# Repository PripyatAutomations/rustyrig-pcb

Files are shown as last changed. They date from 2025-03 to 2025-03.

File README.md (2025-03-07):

You probably want no part of this.
I'm learning KiCad by cobbling together some radio bits to hook to my USRP...

Eventually this might become a free standing transceiver for use with a host
computer for remote operation.

There is no front panel user interface, besides power LED and fault # LED
display.

-------------------------------------------

Current experiment consists of the following bits:
* raspberry pi 4b 8gb running devuan 64bit
* radioberry v2 RF frontend
* the RF amplifier, filters, and antenna matching unit.

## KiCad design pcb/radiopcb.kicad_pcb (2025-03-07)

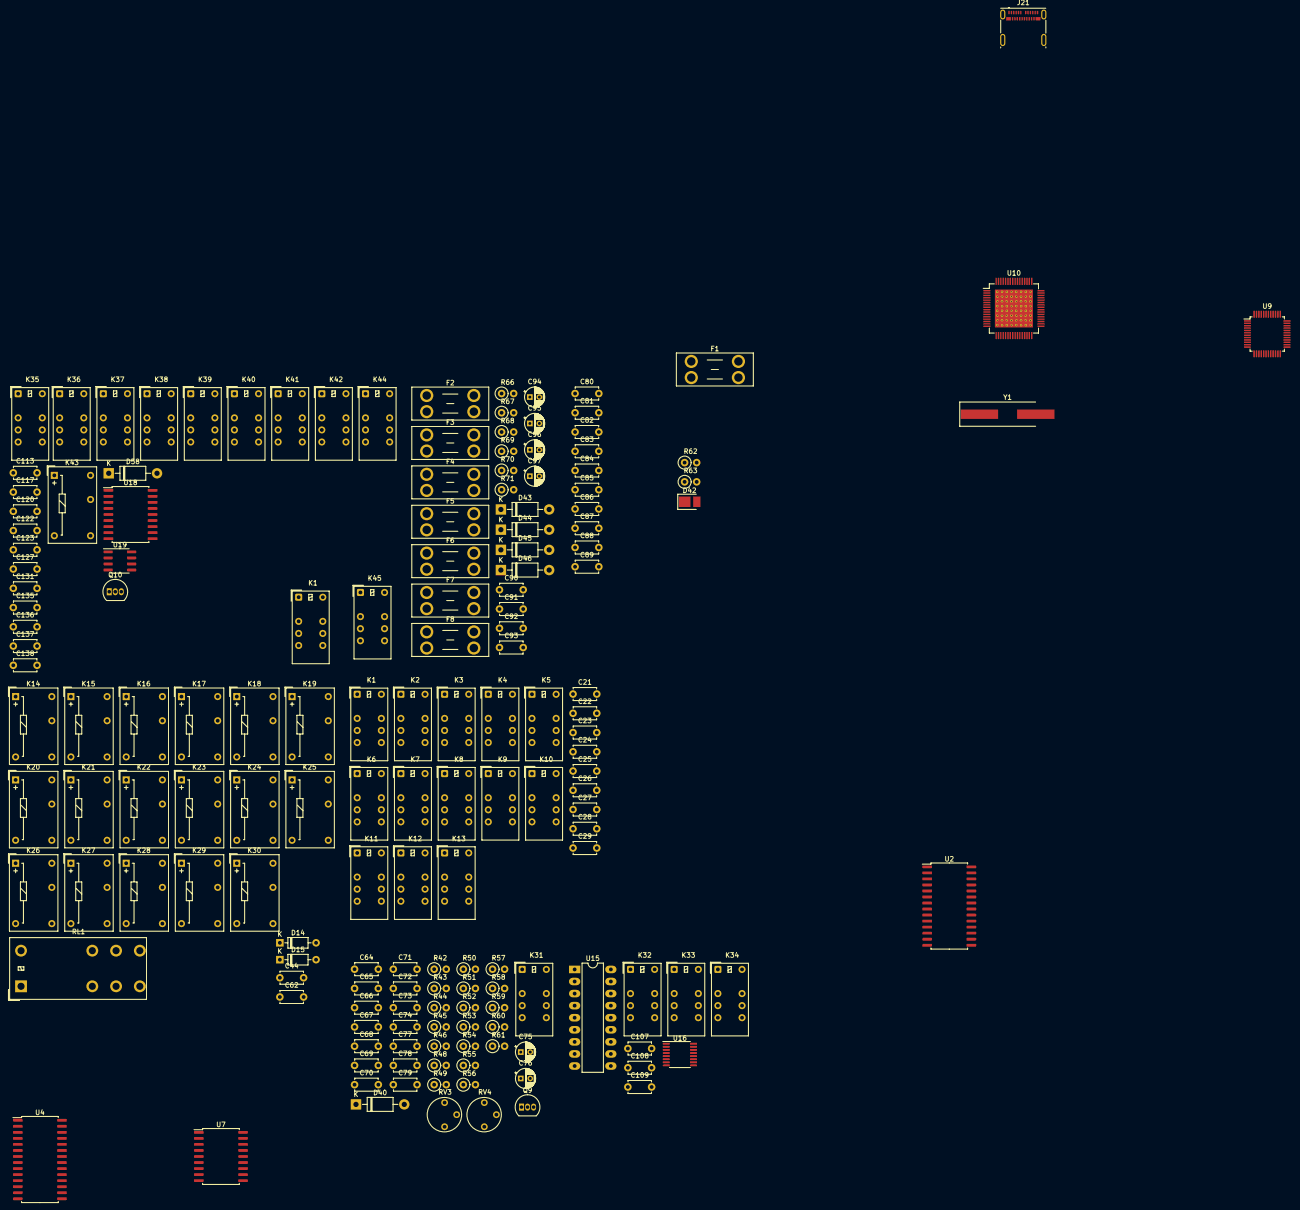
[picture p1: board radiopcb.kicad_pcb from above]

Board: 2 copper layers, 165 parts (0 on the bottom side), 130 nets, no tracks yet.

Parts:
C21, C22, C23, C24, C25, C26, C27, C28, C29, C44, C62, C64, C65, C66, C67, C68, C69, C70, C71, C72, C73, C74, C77, C78, C79, C80, C81, C86, C87, C88, C89, C107, C108, C109, C113, C117, C120, C122, C123, C127, C131, C135, C136, C137, C138: 0.1u; C_Disc_D4.7mm_W2.5mm_P5.00mm
C75, C76: 470u; CP_Radial_D4.0mm_P2.00mm
C82, C83, C90: 10u; C_Disc_D4.7mm_W2.5mm_P5.00mm
C84, C85: 18p; C_Disc_D4.7mm_W2.5mm_P5.00mm
C91, C92: 100n; C_Disc_D4.7mm_W2.5mm_P5.00mm
C93: 47u; C_Disc_D4.7mm_W2.5mm_P5.00mm
C94, C95: 220u; CP_Radial_D4.0mm_P2.00mm
C96, C97: 10u; CP_Radial_D4.0mm_P2.00mm
D14, D15: 1N4148; D_DO-35_SOD27_P7.62mm_Horizontal
D40, D43, D44, D45, D46, D58: 1N4001; D_DO-41_SOD81_P10.16mm_Horizontal
D42: LED-Green; LED_PLCC_2835_Handsoldering
F1, F6: 3A; Fuseholder_Blade_Mini_Keystone_3568
F2, F3: 30A; Fuseholder_Blade_Mini_Keystone_3568
F4, F5: 5A; Fuseholder_Blade_Mini_Keystone_3568
F7, F8: 250mA; Fuseholder_Blade_Mini_Keystone_3568
J21: USB; USB_C_Receptacle_Molex_105450-0101
K1, K1#2, K2, K3, K4, K5, K6, K7, K8, K9, K10, K11, K12, K13, K31, K32, K33, K34, K35, K36, K37, K38, K39, K40, K41, K42, K44, K45: EC2-5SNU; Relay_DPDT_Kemet_EC2
K14, K15, K16, K17, K18, K19, K20, K21, K22, K23, K24, K25, K26, K27, K28, K29, K30, K43: G6E; Relay_SPDT_Omron_G6E
Q9: 2N3904; TO-92_Inline
Q10: BT169B; TO-92_Inline
R42, R43, R52, R53: 1K; R_Axial_DIN0207_L6.3mm_D2.5mm_P2.54mm_Vertical
R44, R45, R48, R49, R50, R51, R54, R55: 22; R_Axial_DIN0207_L6.3mm_D2.5mm_P2.54mm_Vertical
R46, R56: 2.2K; R_Axial_DIN0207_L6.3mm_D2.5mm_P2.54mm_Vertical
R57, R58: 47; R_Axial_DIN0207_L6.3mm_D2.5mm_P2.54mm_Vertical
R59, R60: 220; R_Axial_DIN0207_L6.3mm_D2.5mm_P2.54mm_Vertical
R61: 1k; R_Axial_DIN0207_L6.3mm_D2.5mm_P2.54mm_Vertical
R62, R68, R69, R70, R71: 10M; R_Axial_DIN0207_L6.3mm_D2.5mm_P2.54mm_Vertical
R63: 9.53K; R_Axial_DIN0207_L6.3mm_D2.5mm_P2.54mm_Vertical
R66: 10k; R_Axial_DIN0207_L6.3mm_D2.5mm_P2.54mm_Vertical
R67: 54.9k; R_Axial_DIN0207_L6.3mm_D2.5mm_P2.54mm_Vertical
RL1: Bypass; Relay_DPDT_Panasonic_JW2
RV3, RV4: 10K; Potentiometer_Vishay_T7-YA_Single_Vertical
U2, U4: MCP23017_SO; SOIC-28W_7.5x17.9mm_P1.27mm
U7, U18: MCP23008-xSO; SOIC-18W_7.5x11.6mm_P1.27mm
U9: CM119B; TQFP-48_7x7mm_P0.5mm
U10: TUSB4041I; HTQFP-64-1EP_10x10mm_P0.5mm_EP8x8mm_Mask4.4x4.4mm_ThermalVi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
U15: ULN2804A; DIP-18_W7.62mm_LongPads
U16: 74HC596; TSSOP-16_4.4x5mm_P0.65mm
U19: LM555xM; SOIC-8_3.9x4.9mm_P1.27mm
Y1: 24Mhz; Crystal_SMD_HC49-SD_HandSoldering

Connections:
+1V1: C82.1, F8.1, U10.19 (VDD), U10.25 (VDD), U10.37 (VDD), U10.45 (VDD), U10.53 (VDD), U10.60 (VDD), U10.63 (VDD)
+3.3V: C83.1, F7.1, U9.7 (PWRSEL), U9.38 (MSEL), U10.2 (VDD33), U10.20 (VDD33), U10.31 (VDD33), U10.48 (VDD33)
+5V: C23.2, C24.2, C44.2, C62.2, C80.1, C81.1, C89.1, C122.2, F1.1, F6.2, K32.1, K33.1, K34.1, Q9.3 (C), U2.9 (VDD), U4.9 (VDD), U4.15 (A0), U7.4 (A1), U7.18 (VDD), U9.29 (AVDD), U9.34 (AVDD), U9.35 (DVDD), U18.18 (VDD)
+12V: C21.2, C76.1, C79.2, C120.2, F5.1, K1.1, K1#2.1, K2.1, K3.1, K4.1, K5.1, K6.1, K7.1, K8.1, K9.1, K10.1, K11.1, K12.1, K13.1, K14.1, K15.1, K16.1, K17.1, K18.1, K19.1, K20.1, K21.1, K22.1, K23.1, K24.1, K25.1, K26.1, K27.1, K28.1, K29.1, K30.1, K35.1, K36.1, K37.1, K38.1, K39.1, K40.1, K41.1, K42.1, K44.1, K45.1, RL1.1
+BATT: F3.1, F3.2, F4.1, F5.2
Earth: C21.1, C22.1, C23.1, C24.1, C25.2, C26.2, C27.2, C28.2, C29.2, C44.1, C62.1, C65.1, C68.1, C68.2, C69.1, C74.1, C75.2, C76.2, C77.1, C78.1, C79.1, C80.2, C81.2, C82.2, C83.2, C84.2, C85.2, C86.2, C87.2, C88.2, C89.2, C107.1, C108.1, C109.1, C113.1, C117.1, C120.1, C122.1, C123.1, C127.1, C131.1, C135.1, C136.1, C137.2, C138.2, D42.1 (K), J21.A1 (GND), J21.A5 (CC1), J21.A8 (SBU1), J21.A12 (GND), J21.B1 (GND), J21.B5 (CC2), J21.B8 (SBU2), J21.B12 (GND), J21.S1 (SHIELD), K31.8, R48.1, R49.2, R50.1, R51.2, R54.1, R55.2, R56.1, R63.1, RV3.3, RV4.3, U2.10 (VSS), U2.15 (A0), U2.16 (A1), U2.17 (A2), U4.10 (VSS), U4.16 (A1), U4.17 (A2), U7.3 (A2), U7.5 (A0), U7.9 (VSS), U9.10 (MODE), U10.65 (VSS), U15.9 (GND), U16.8 (GND), U18.3 (A2), U18.4 (A1), U18.5 (A0), U18.9 (VSS), Y1.2
GND: C90.1, C91.1, C93.2, C94.2, C95.2, C96.2, C97.2, D58.2 (A), F2.2, K43.6, R66.1, R69.2, R71.2, U19.1 (GND)
GNDA: U9.24 (AVSS), U9.33 (AVSS)
GNDD: U9.14 (DVSS), U9.36 (DVSS)
unnamed: K1.5, K1#2.5
unnamed: K1.8, K1#2.8
unnamed: C64.2, R42.1, R43.2, R44.2
unnamed: C66.2, R48.2, R53.1
unnamed: C67.2, R49.1, R52.1
unnamed: C69.2, R57.2, RV3.2
unnamed: C70.2, C73.1, R57.1
unnamed: C71.2, C72.2, R58.1
unnamed: C72.1, R59.1
unnamed: C73.2, R60.1
unnamed: C74.2, R58.2, RV4.2
unnamed: C75.1, C78.2
unnamed: C93.1, C94.1, C95.1, R67.2
unnamed: K1.12, K1#2.12
unnamed: C22.2, K8.12
unnamed: C25.1, K9.12
unnamed: C26.1, K10.12
unnamed: C27.1, K11.12
unnamed: C28.1, K12.12
unnamed: C29.1, K13.12
unnamed: D40.2 (A), K31.12
unnamed: D40.1 (K), K31.1
unnamed: D42.2 (A), U9.12 (LEDO)
unnamed: C97.1, D43.2 (A), D44.1 (K), D45.1 (K), F7.2, R68.1
unnamed: C96.1, D43.1 (K), F6.1
unnamed: D44.2 (A), R68.2, R69.1
unnamed: D45.2 (A), D46.1 (K), F8.2, R70.1
unnamed: D46.2 (A), R70.2, R71.1
unnamed: K32.12, U15.11 (O8)
unnamed: K33.12, U15.12 (O7)
unnamed: K34.12, U15.13 (O6)
unnamed: C113.2, K35.12
unnamed: C117.2, K36.12
unnamed: C123.2, K37.12
unnamed: C127.2, K38.12
unnamed: C131.2, K39.12
unnamed: C135.2, K40.12
unnamed: C136.2, K41.12
unnamed: C137.1, K42.12
unnamed: D58.1 (K), K43.1
unnamed: C138.1, K44.12
unnamed: K1#2.4, K45.8
unnamed: U4.13 (SDA), U7.2 (SDA)
unnamed: U4.12 (SCK), U7.1 (SCL)
unnamed: K31.5, K31.10
unnamed: U16.11 (SRCLK), U16.12 (RCLK)
unnamed: C107.2, C108.2, C109.2, U15.10 (COM), U16.16 (VCC)
unnamed: K1.4, K13.4
unnamed: K1.3, K1.10, K1#2.3, K1#2.10
unnamed: K2.4, K45.9
unnamed: K2.9, K3.4
unnamed: K2.3, K2.10
unnamed: K3.9, K4.4
unnamed: K3.3, K3.10
unnamed: K4.9, K5.4
unnamed: K4.3, K4.10
unnamed: K5.9, K6.4
unnamed: K5.3, K5.10
unnamed: K6.9, K7.4
unnamed: K6.3, K6.10
unnamed: K7.9, K8.4
unnamed: K7.3, K7.10
unnamed: K8.3, K8.10
unnamed: K9.3, K9.10
unnamed: K10.4, K11.9
unnamed: K9.4, K10.9
unnamed: K10.3, K10.10
unnamed: K11.4, K12.9
unnamed: K11.3, K11.10
unnamed: K12.4, K13.9
unnamed: K12.3, K12.10
unnamed: K13.3, K13.10
unnamed: K14.7, K15.7, K16.7, K17.7, K18.7, K19.7, K20.7, K21.7, K22.7
unnamed: K22.10, K26.7, K29.7, RL1.5
unnamed: K22.12, K25.7, RL1.4
unnamed: K23.7, K24.10
unnamed: K23.10, K27.10, K30.7
unnamed: K24.7, K25.10
unnamed: K27.7, K28.10
unnamed: K28.7, K29.10
unnamed: K32.4, K33.9
unnamed: K32.3, K32.10
unnamed: K33.4, K34.9
unnamed: K33.3, K33.10
unnamed: K34.3, K34.10
unnamed: K35.4, K36.9
unnamed: K35.3, K35.10
unnamed: K36.4, K37.9
unnamed: K36.3, K36.10
unnamed: K37.4, K38.9
unnamed: K37.3, K37.10
unnamed: K38.4, K39.9
unnamed: K38.3, K38.10
unnamed: K39.4, K40.9
unnamed: K39.3, K39.10
unnamed: K40.4, K41.9
unnamed: K40.3, K40.10
unnamed: K41.3, K41.10
unnamed: K42.3, K42.10
unnamed: K44.3, K44.10
unnamed: K45.3, K45.10
unnamed: Q9.2 (B), R61.2
unnamed: C77.2, Q9.1 (E), RV3.1, RV4.1
unnamed: R42.2, R44.1, R45.1
unnamed: RL1.2, RL1.7
unnamed: C65.2, R46.1
unnamed: U9.42 (USBDM), U10.57 (USB_DM_DN4)
unnamed: U9.41 (USBDP), U10.56 (USB_DP_DN4)
unnamed: R63.2, U10.32 (USB_R1)
unnamed: C84.1, R62.2, U10.30 (XI)
unnamed: C85.1, R62.1, U10.29 (XO), Y1.1
unnamed: C90.2, C91.2, F4.2
unnamed: R66.2, R67.1
unnamed: U15.1 (I1), U16.15 (QA)
unnamed: U15.2 (I2), U16.1 (QB)
unnamed: U15.3 (I3), U16.2 (QC)
unnamed: U15.4 (I4), U16.3 (QD)
unnamed: U15.5 (I5), U16.4 (QE)
unnamed: U15.6 (I6), U16.5 (QF)
unnamed: U15.7 (I7), U16.6 (QG)
unnamed: U15.8 (I8), U16.7 (QH)

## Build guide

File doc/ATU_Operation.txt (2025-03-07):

In order to reduce costs and use cheaply available relays, some compromises
were made. Not the end of the world as we can reliably sequence things in software.

All switching of relays carrying RF should *ONLY* be done after activating (lowering) the
TX_INHIBIT signal, to prevent hot switching the relay!

The stm32 will output this on a dedicated digital GPIO pin, in an ACTIVE LOW state.

The values for the L and C components were chosen to match the LDG AT-11 values but
the control and switching is my own design, inspired by ubitx.

By default, the ATU is bypassed by RL_BYPASS's NC contacts. When the ATU is desired,
RL_BYPASS coil should be energized.

RL_HI_Z moves the C component between inside/outside of the L network for easy
low/high Z selection.

SWR bridge provides real-time monitoring of forward and reverse power in the
antennae system and allows shutdown for high SWR to protect the finals.
